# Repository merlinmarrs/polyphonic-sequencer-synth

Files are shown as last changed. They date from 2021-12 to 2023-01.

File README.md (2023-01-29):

# polyphonic-sequencer-synth

**WARNING: This device could destroy your computer's USB port or USB adapter. This device also flashes at high frequency and is an epilepsy risk.**

*NOTE: Not all 74HC14 ICs work for this circuit. Elliot Williams uses the CD40106BE instead. Make sure your 74HC14 has Schmitt trigger with hysteresis and maybe order a couple different brands to be sure. I find that Nexperia ICs work well and not I have had bad luck with Diodes Incorporated.

A mini sequencer and polyphonic synth based directly on Elliot Williams' epic Logic Noise series from Hackaday (https://hackaday.com/2015/02/04/logic-noise-sweet-sweet-oscillator-sounds/).

The boards were designed and manufactured at Fablab Digiscope in Orsay France, which is run by Romain Di Vozzo, by Jonah Marrs with funding from La Diagonale U Paris Saclay. Here's a video of the workshop and the board in action: https://vimeo.com/653720316

Selena Pere has made an beautiful inferface for a version 2 of this device. 

The sequencer portion is an 8-bit looper using a 595 shift register (and a second 595 just to make the corresponding LEDs blink). Bits can be added in LOOP mode by pushing the BEAT button. Beats are automatically added in AUTO mode by synchronizing the CLK and DATA knobs at the far right. The green LED is connected to the CLK frequency. 

The jumpers can trigger one of three notes everytime that corresponding LED flashes. The timber of each note can be varied by turning the pots marked A, B and C. 

The notes are passively mixed in a final stage and can be either output to the onboard buzzer or send to the 3.5mm audio out with OUT selected on the second slide switch. 

The board can be powered by USB C or with a 5V power supply connected to the power header. 

Notes:
-For the device to make predictable sound, there should be at least one jumper going to notes A, B and C from the loop sequence header. 
-If the clock is set too fast it will saturate the shift register resulting in a full set of beats. To remove the beats, turn to AUTO mode and find a combination of CLK and DATA that produces no beats, and then switch back to LOOP mode once the beats have been cleared to make your own pattern. 
-You have to push down hard enough to activate the mini metal button and if the clock is going super slow it might seem likes it's impossible to add beats. Either speed up the CLK or hold the button longer than you would expect is necessary :).
-If you change the output mixing resistors you can change the output volume.

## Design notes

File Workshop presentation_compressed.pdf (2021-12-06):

# Free Synthesizer Workshops @ Fablab Digiscope | LISN

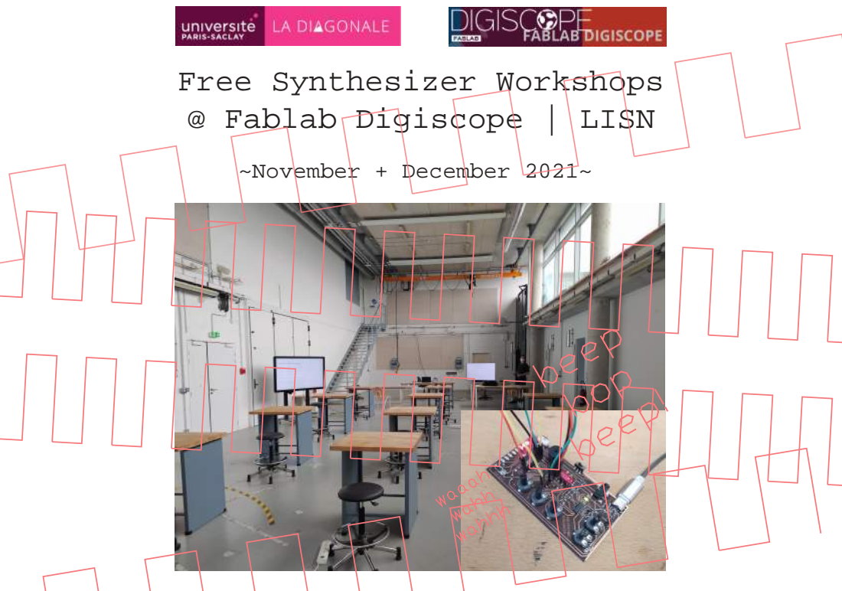
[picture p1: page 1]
~November + December 2021~; beep bop beep!; waaah wahh wahhh

# SAFETY

# THIS BOARD IS

# -IT IS UNINSULATED -IT COULD DAMAGE YOUR PC -YOU SHOULD NOT LEAVE IT PLUGGED IN UNATTENDED -RISK OF EPILEPTIC SEIZURES

# COMMENT SOUDER

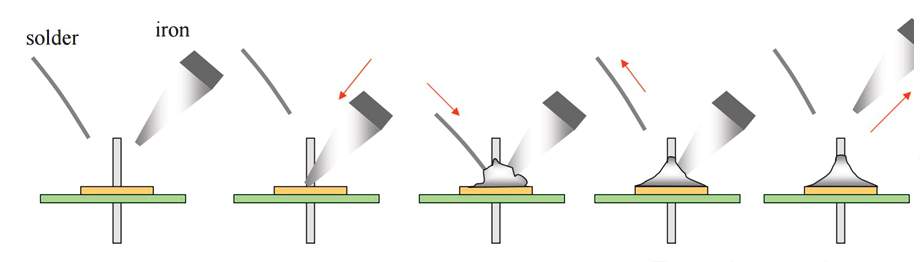
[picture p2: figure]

# IT GETS HOT!

# WASH YOUR HANDS BEFORE YOU EAT (LEAD IN THE SOLDER)

# ASSEMBLY

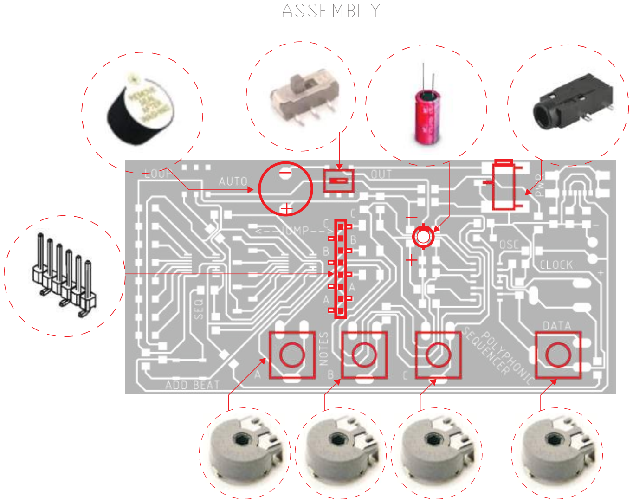
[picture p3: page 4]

# CAPACITOR STORES ELECTRICAL ENERGY HI FREQ PASSES WHILE LOW FREQ BLOCKED

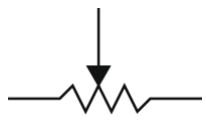
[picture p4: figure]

# POTENTIOMETER A VARIABLE RESISTOR CONTROLS VOLUME IN YOUR STEREO

# SWITCH ALLOWS US TO CONNECT / DISCONNECT BETWEEN TWO OPTIONS LIKE AM / FM ON A RADIO

# PIEZO BUZZER A MINI SPEAKER THAT VIBRATES TO CREATE SOUND

# OPERATION

HIT | TO

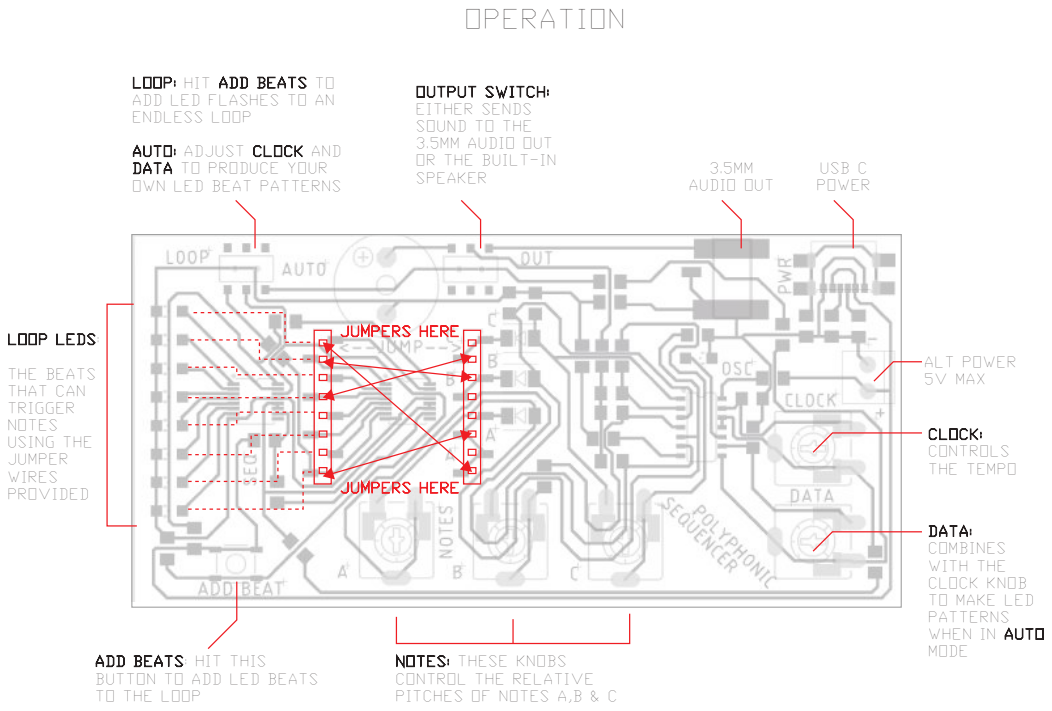
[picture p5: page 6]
ADJUST; AND; : HIT THIS; THESE KNOBS; 3.5MM AUDIO OUT; USB C POWER; ALT POWER 5V MAX; CONTROLS THE TEMPO; THE BEATS THAT CAN TRIGGER NOTES USING THE JUMPER WIRES PROVIDED

ADD LED FLASHES TO AN
ENDLESS LOOP

EITHER SENDS
SOUND TO THE
3.5MM AUDIO OUT
OR THE BUILT-IN
SPEAKER

TO PRODUCE YOUR
OWN LED BEAT PATTERNS

COMBINES
WITH THE
CLOCK KNOB
TO MAKE LED
PATTERNS
WHEN IN
MODE

BUTTON TO ADD LED BEATS
TO THE LOOP

CONTROL THE RELATIVE
PITCHES OF NOTES A,B & C

# RESEARCH

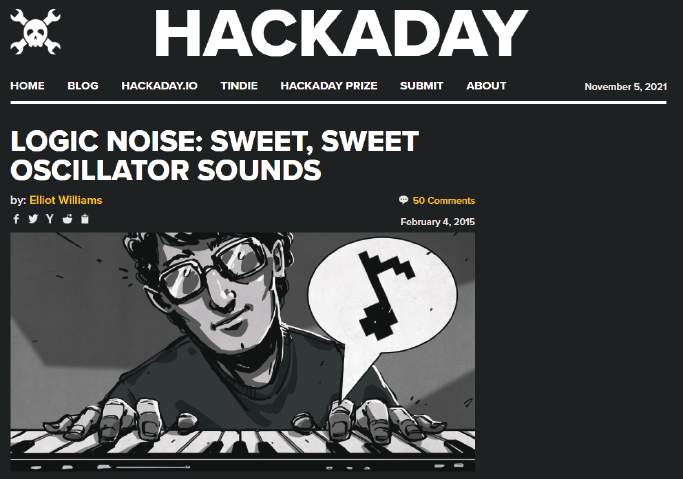
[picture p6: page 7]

# PROTOTYPING

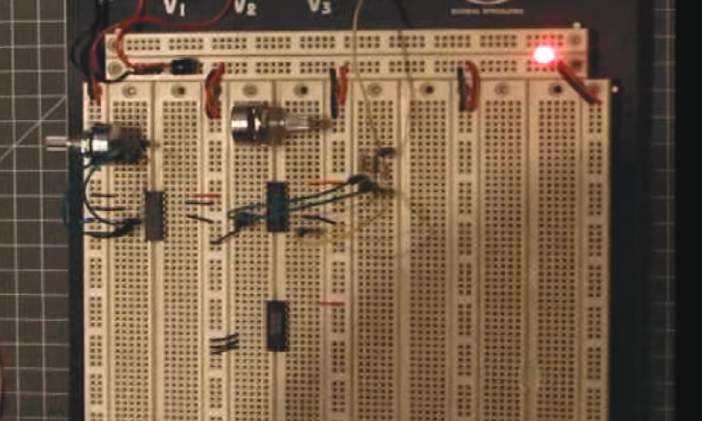
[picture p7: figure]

# SOURCING

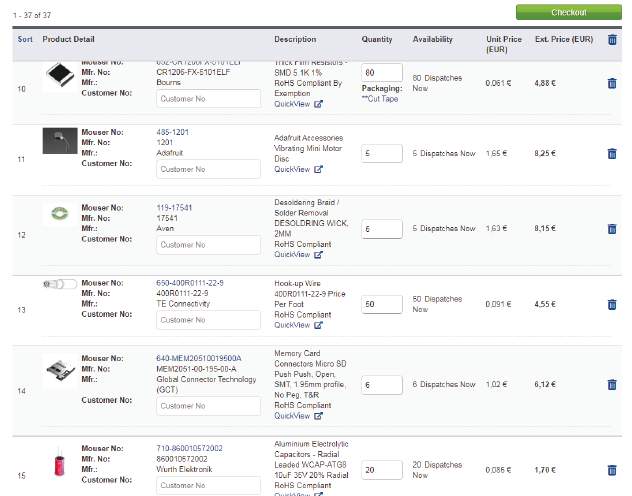
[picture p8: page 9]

# DESIGN

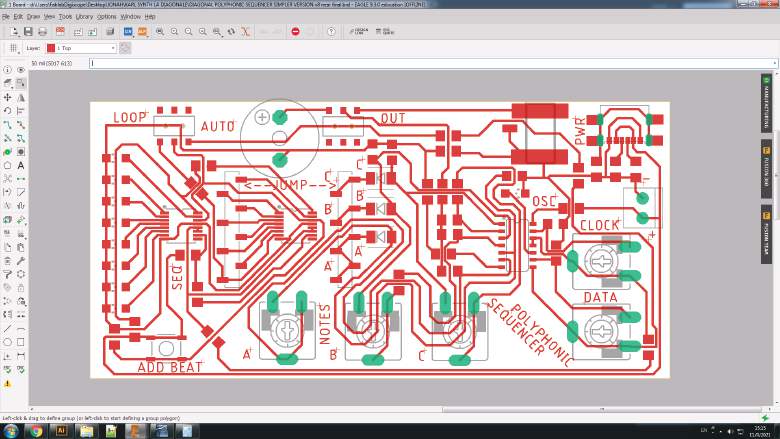
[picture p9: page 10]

# PRODUCTION

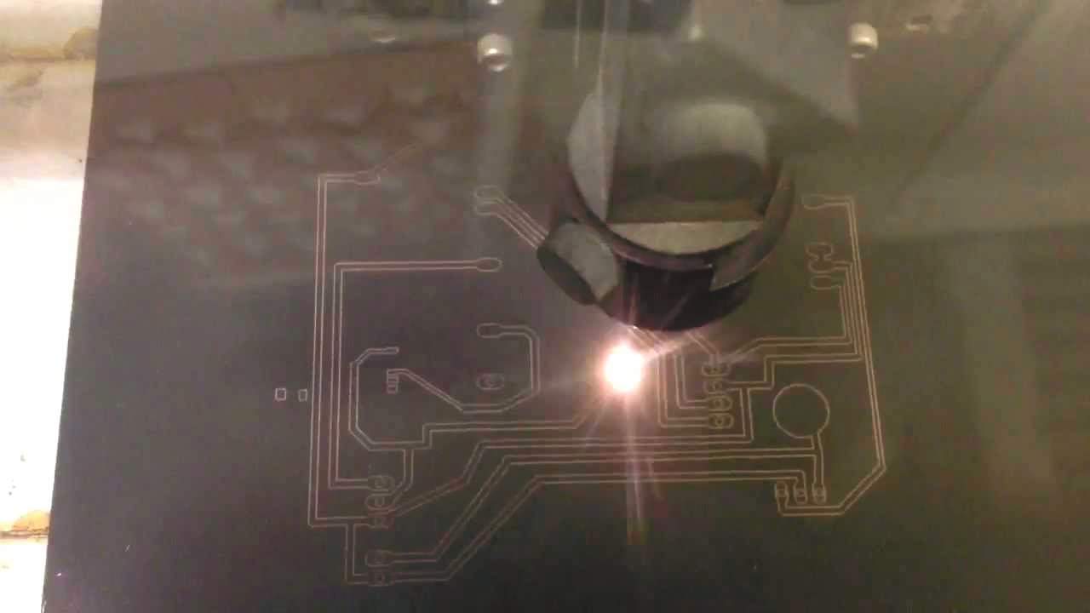
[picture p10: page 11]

# INVERTER

YES | NO

# INVERTER

NO | YES

# INVERTER

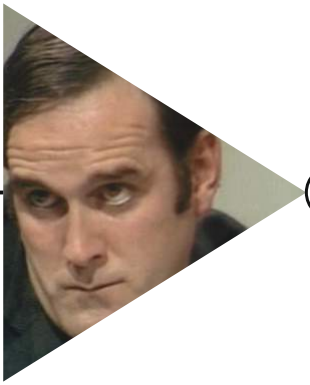
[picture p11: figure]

“YES,

# I DID!”

“NO,

# YOU DIDN’T”

# DIDN’T”

# INVERTER

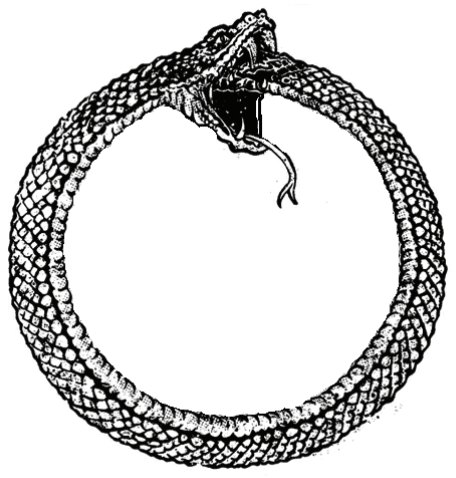
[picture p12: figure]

# YES

t = 0

# delay

# YES

# INVERTER

t = 1

# delay

NO | NO

# INVERTER

t = 0 | 1 | 2 | 3 | 4

# NO YES NO YESNO

# Sound Is Just Wiggly Air !

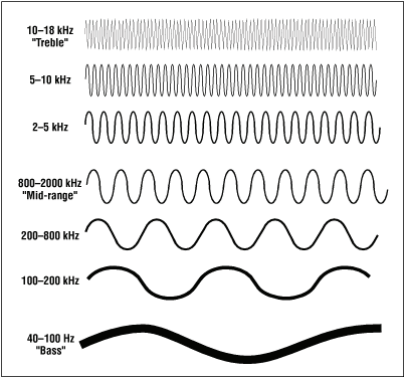
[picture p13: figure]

# PIEZO SPEAKER

# SWAMP

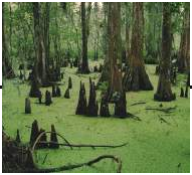
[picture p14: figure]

OPERATION | OPERATION

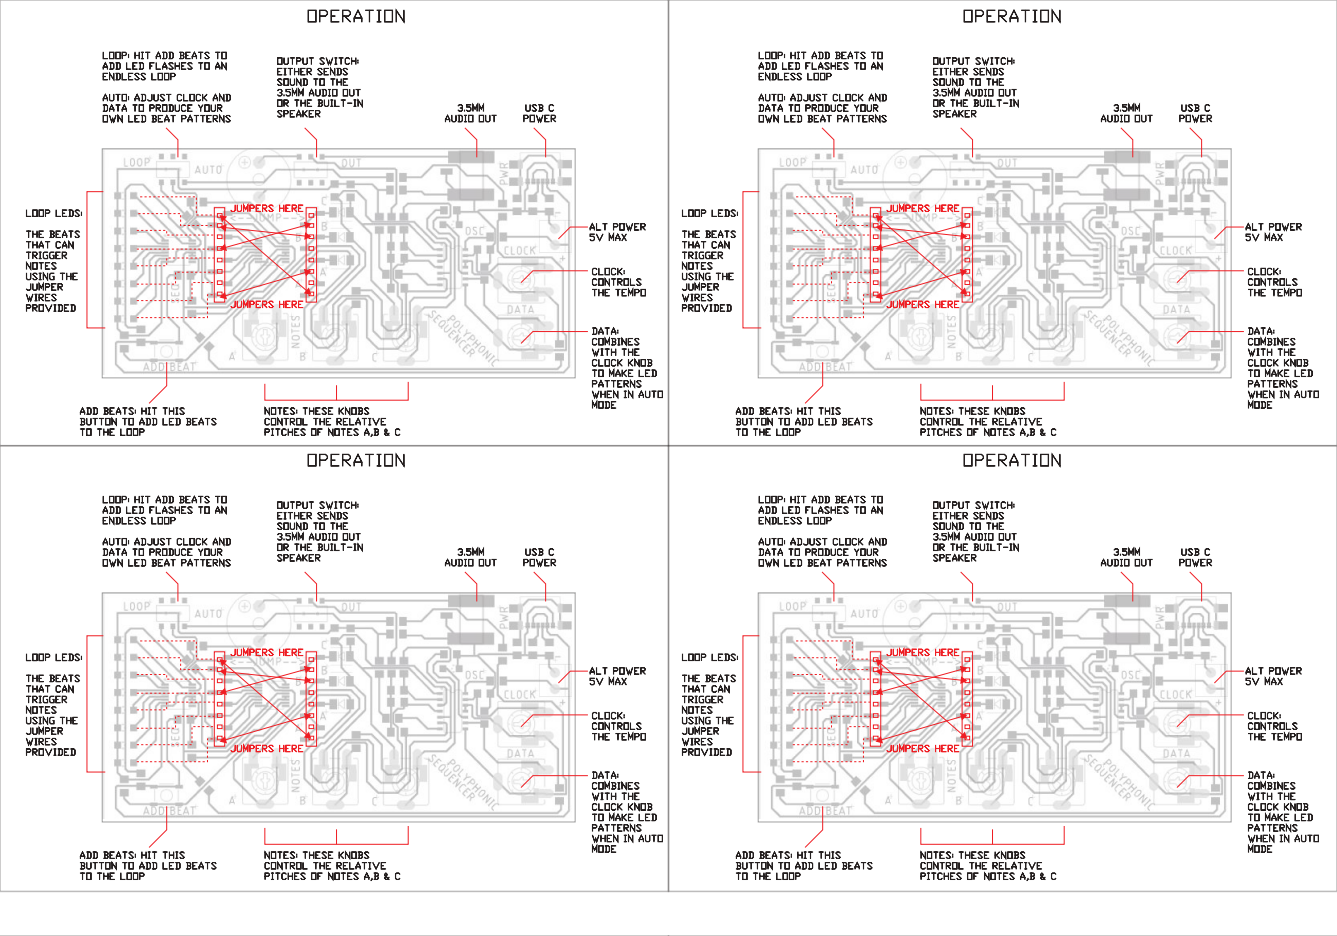
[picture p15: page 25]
OPERATION; HIT; ADD; LED; FLASHES TO; ENDLESS LOOP; ADJUST; AND; PRODUCE YOUR; OWN; LED BEAT PATTERNS; SOUND TO; THE; 3.5MM AUDIO; OUT; HIT THIS; BUTTON TO; LED BEATS; LOOP; THESE KNOBS; PITCHES; OF NOTES A,B & C; AUDIO; USB C POWER; ALT POWER 5V MAX; CONTROLS THE TEMPO; COMBINES; WITH; CLOCK KNOB; MAKE LED; PATTERNS WHEN IN MODE; THE BEATS THAT CAN TRIGGER NOTES USING THE JUMPER WIRES PROVIDED; LED FLASHES TO; ENDLESS; MAKE; LOOP:; HIT ADD BEATS TO; DATA TO; 3.5MM AUDIO OUT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

EITHER SENDS
OR THE BUILT-IN
SPEAKER

SOUND TO THE

CONTROL THE RELATIVE

ADD LED FLASHES TO AN
ENDLESS LOOP

OUTPUT SWITCH:

3.5MM AUDIO OUT

AUTO: ADJUST CLOCK AND

TO PRODUCE YOUR
OWN LED BEAT PATTERNS

COMBINES
WITH THE
CLOCK KNOB
TO MAKE LED
PATTERNS
WHEN IN
MODE

ADD BEATS: HIT THIS
BUTTON TO ADD LED BEATS
TO THE LOOP

NOTES: THESE KNOBS
PITCHES OF NOTES A,B & C

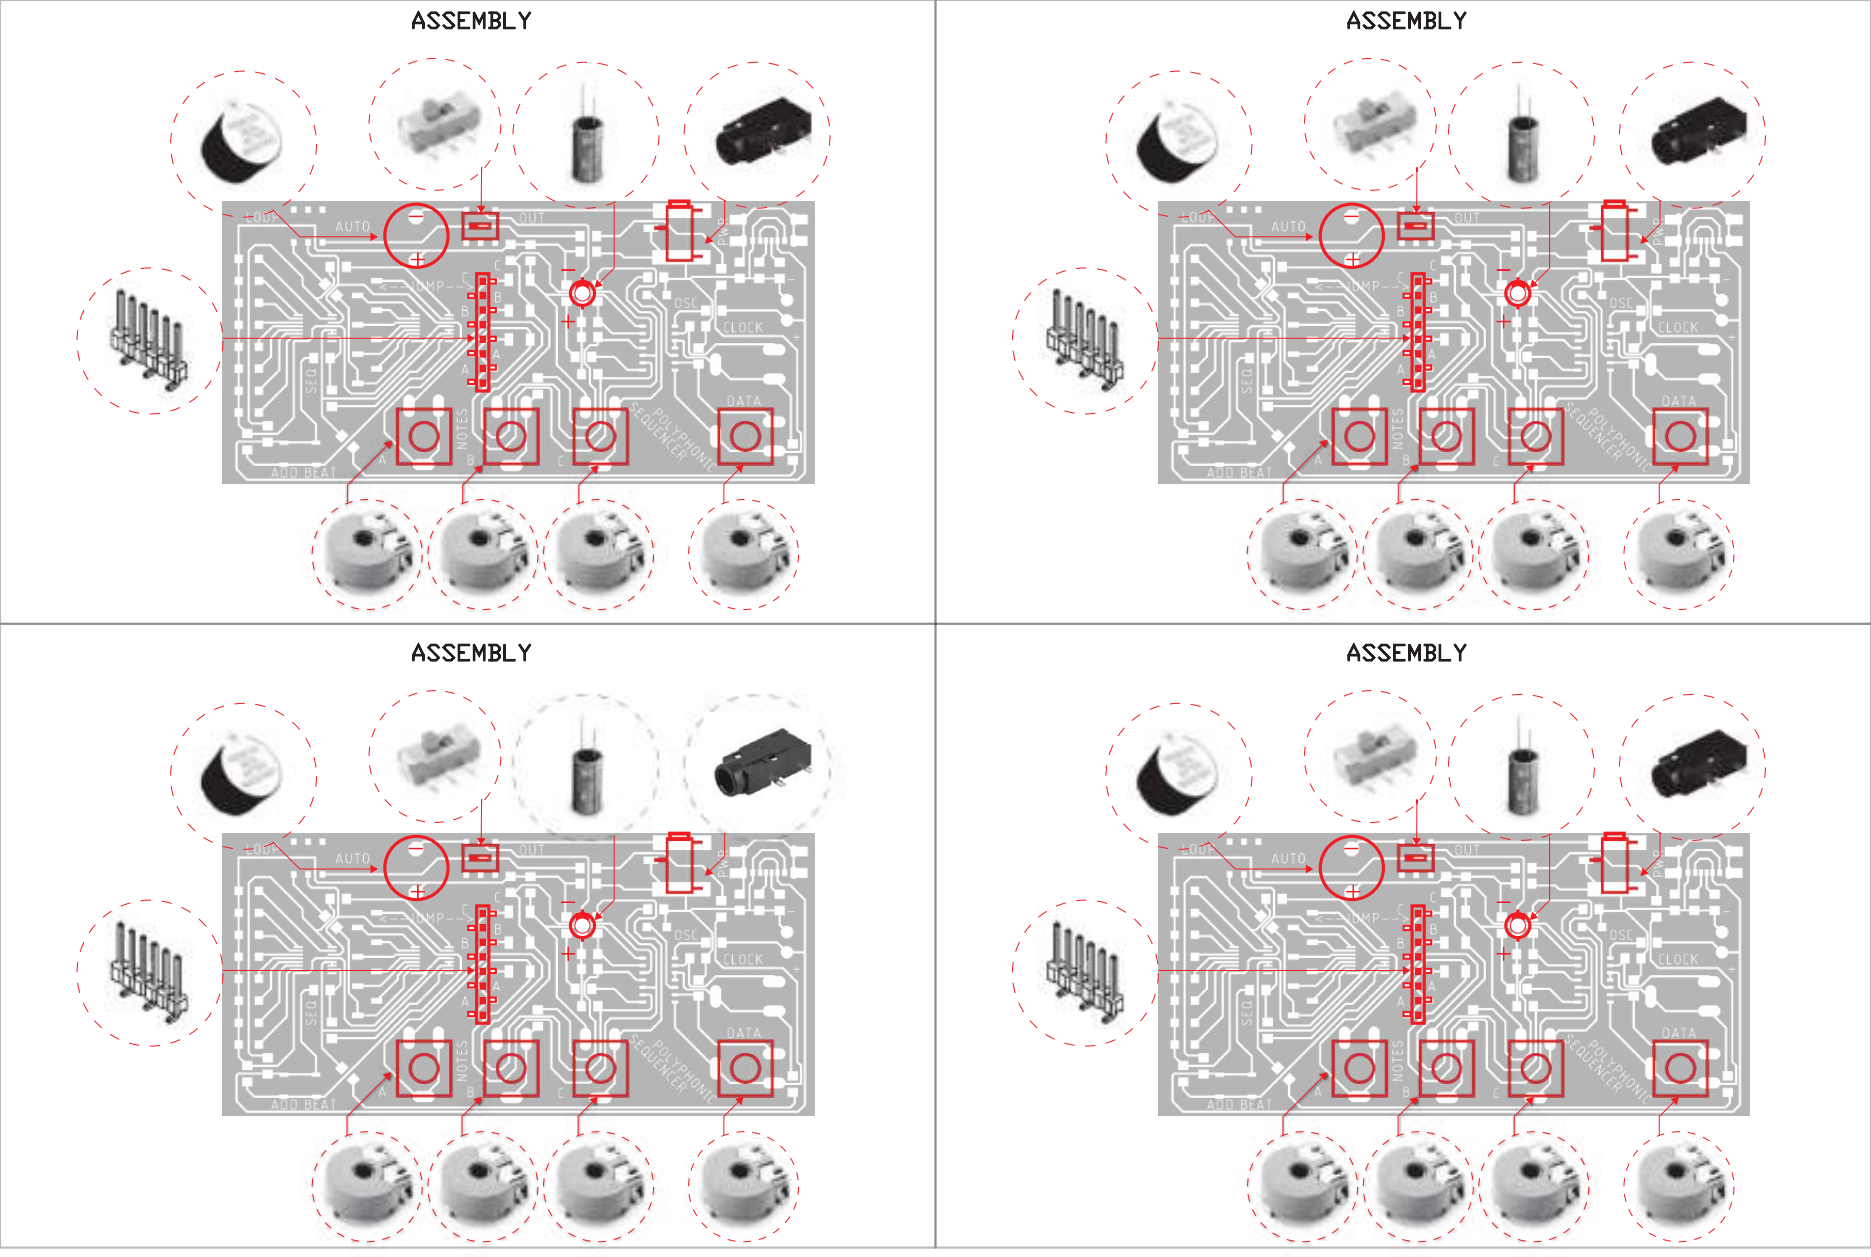
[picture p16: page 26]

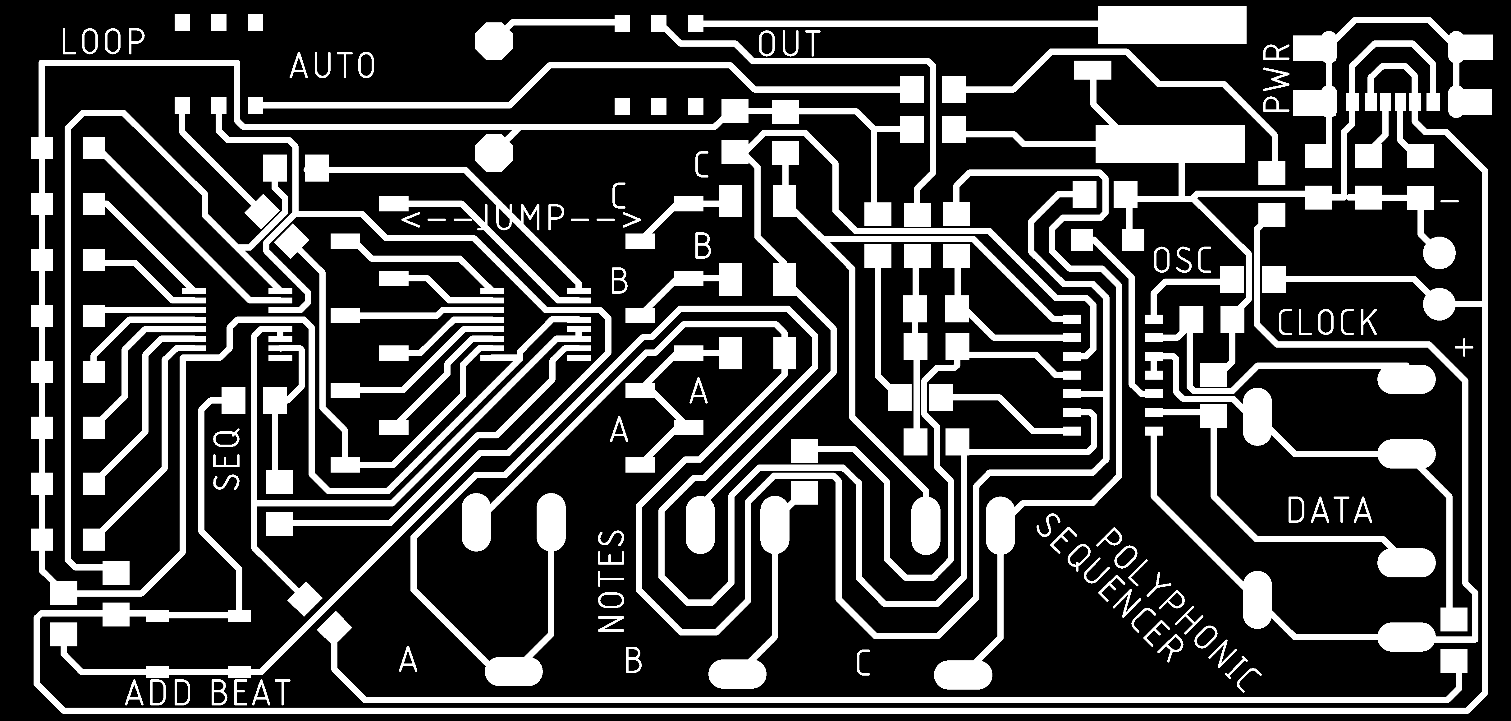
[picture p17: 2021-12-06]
polyphonic sequencer v9 TO CUT inverted.png

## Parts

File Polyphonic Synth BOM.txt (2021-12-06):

BOM:

x1 Hex inverter with Schmitt-Trigger Inputs 74HC14 *in SOIC-14*
https://www.mouser.fr/ProductDetail/Texas-Instruments/SN74HC14NS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

x2 Shift register 74HC595PW-Q100 *in TSSOP-16* :
https://www.mouser.fr/ProductDetail/771-74HC595PW-Q100

x1 USB C port :
https://www.mouser.fr/ProductDetail/640-USB4125-GF-A

x5 50K pot PS10MV50-503A3030:
https://www.mouser.fr/ProductDetail/531-PS10MV50503A3030

x4 Black knobs 5119NE:
https://www.mouser.fr/ProductDetail/531-5119NE

x1 Cream shaft 5116:
https://www.mouser.fr/ProductDetail/531-5116

x1 button PTS526 SK15 SMTR2 LFS:
https://www.mouser.fr/ProductDetail/611-PTS526SK15SMR2L

x2 slide switch JS202011SCQN:
https://www.mouser.fr/ProductDetail/611-JS202011SCQN

x1 set of 8 female-female jumpers ZW-FF-10:
https://www.mouser.fr/ProductDetail/854-ZW-FF-10

x3 SMD diodes BAS321,115:
https://www.mouser.fr/ProductDetail/771-BAS321-T-R 

x2 SMD header 1x8 87898-0826:
https://www.mouser.fr/ProductDetail/538-87898-0826

x1 buzzer 
https://www.mouser.fr/ProductDetail/665-AT1224TWT5V2R

x1 3.5mm jack SJ2-35853A-SMT-TR:
https://www.mouser.fr/ProductDetail/490-SJ2-35853ASMT-TR

x1 header screw terminal
https://www.mouser.fr/ProductDetail/651-1984167

Generic components:

x1 green 1206 SMD LED

x8 red 1206 SMD LED

x2 47uF SMD 1206 cap

x15 0ohm jumper 1206 SMD LED

x1 0.1uF SMD 1206 cap

x1 1uF SMD 1206 cap

x1 10uF SMD 1206 cap

x1 100uF cap

x2 10K SMD 1206 resistor

x3 100ohm SMD 1206 resistor

x2 5k1 SMD 1206 resistor

x1 1M SMD 1206 resistor

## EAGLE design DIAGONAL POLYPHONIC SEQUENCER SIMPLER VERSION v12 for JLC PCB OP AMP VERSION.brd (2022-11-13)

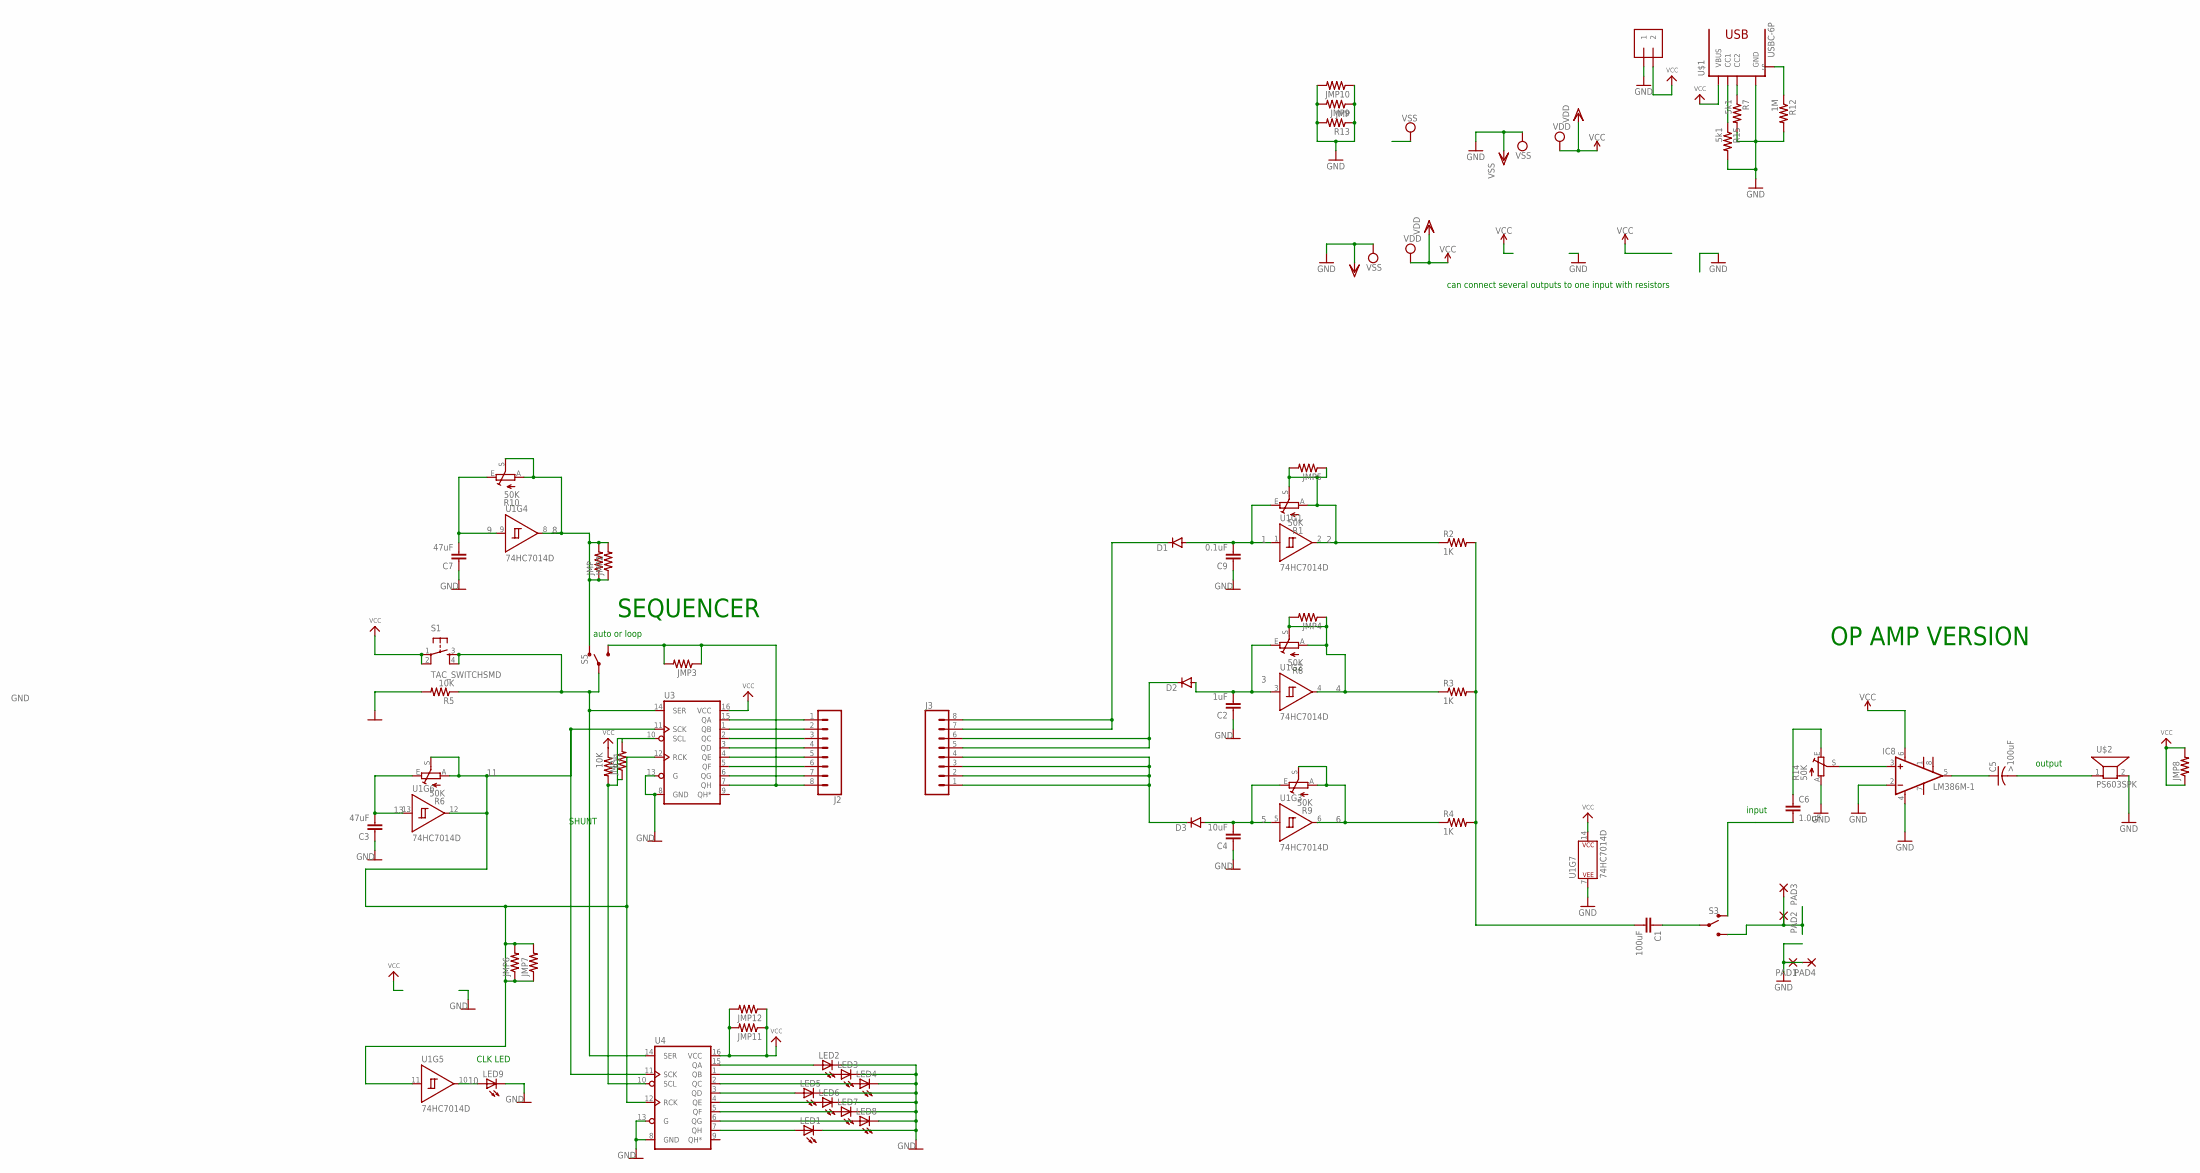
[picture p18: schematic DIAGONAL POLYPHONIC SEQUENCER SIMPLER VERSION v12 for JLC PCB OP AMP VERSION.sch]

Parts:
C1: 100uF; 1206
C2: 1uF; 1206
C3, C7: 47uF; 1206
C4: 10uF; 1206
C5: >100uF; C1206
C6: 1.0uF; 1206
C9: 0.1uF; 1206
D1, D2, D3: DIODEDO214AA; DO-214AA
IC8: LM386M-1; SO08
J1: 1X2-3.5MM
J2, J3: CONN_08SMD-STRAIGHT-ALT-FEMALE; 1X08_SMD_ALT
JMP, JMP1, JMP2, JMP3, JMP4, JMP5, JMP6, JMP7, JMP8, JMP9, JMP10, JMP11, JMP12: R-US_R1206; R1206
LED1, LED2, LED3, LED4, LED5, LED6, LED7, LED8, LED9: LEDCHIPLED_1206; CHIPLED_1206
PAD1, PAD2, PAD3, PAD4: SMD5; SMD2,54-5,08
R1, R6, R8, R9, R10, R14: 50K; CA9V
R2, R3, R4: 1K; R1206
R5, R11: 10K; R1206
R7, R15: 5k1; R1206
R12: 1M; R1206
R13: JMP; R1206
S1: TAC_SWITCHSMD; TACTILE-SWITCH-SMD
S3, S5: SWITCH-SPDT-SMD-AYZ0202; SWITCH_DPDT_SMD_AYZ0202
U1: 74HC7014D; SO14
U3, U4: 74595; TSSOP16
U$1: USBC-6P; USCX-06FX-XXMX-01
U$2: PS603SPK; PS603

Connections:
1: C9.2, D1.A, R1.E, U1.1 (A)
2: JMP5.1, JMP5.2, R1.A, R1.S, R2.1, U1.2 (Y)
3: C2.2, D2.A, R8.E, U1.3 (A)
4: JMP4.1, JMP4.2, R3.1, R8.A, R8.S, U1.4 (Y)
5: C4.2, D3.A, R9.E, U1.5 (A)
6: R4.1, R9.A, R9.S, U1.6 (Y)
8: JMP.1, JMP.2, JMP2.1, JMP2.2, R10.A, R10.S, S5.1 (O), U1.8 (Y)
9: C7.2, R10.E, U1.9 (A)
10: LED9.A, U1.10 (Y)
11: JMP6.1, JMP6.2, JMP7.1, JMP7.2, R6.A, R6.S, U1.11 (A), U1.12 (Y), U3.11 (SCK), U3.12 (RCK), U4.11 (SCK), U4.12 (RCK)
13: C3.2, R6.E, U1.13 (A)
GND: C2.1, C3.1, C4.1, C7.1, C9.1, IC8.2 (-IN), IC8.4 (GND), J1.1, JMP9.1, JMP9.2, JMP10.1, JMP10.2, LED1.C, LED2.C, LED3.C, LED4.C, LED5.C, LED6.C, LED7.C, LED8.C, LED9.C, PAD1.1, PAD4.1, R5.2, R7.2, R12.2, R13.1, R13.2, R14.A, R15.2, U1.7 (P$V-), U3.8 (GND), U3.13 (G), U4.8 (GND), U4.13 (G), U$1.GND1 (GND), U$1.GND2 (GND), U$2.2
unnamed: LED1.A, U4.7 (QH)
unnamed: C1.2, R2.2, R3.2, R4.2
unnamed: LED4.A, U4.2 (QC)
unnamed: R7.1, U$1.CC2
unnamed: LED2.A, U4.15 (QA)
unnamed: LED3.A, U4.1 (QB)
unnamed: C1.1, S3.2
unnamed: J2.1, U3.15 (QA)
unnamed: J2.2, U3.1 (QB)
unnamed: LED7.A, U4.5 (QF)
unnamed: LED6.A, U4.4 (QE)
unnamed: LED8.A, U4.6 (QG)
unnamed: LED5.A, U4.3 (QD)
unnamed: D3.C, J3.1, J3.2, J3.3, J3.4
unnamed: D2.C, J3.5, J3.6
unnamed: R15.1, U$1.CC1
unnamed: J2.3, U3.2 (QC)
unnamed: PAD2.1, PAD3.1, S3.3 (S)
unnamed: C6.2, S3.1 (O)
unnamed: J2.4, U3.3 (QD)
unnamed: R12.1, U$1.SHIELD1 (S), U$1.SHIELD2 (S), U$1.SHIELD3 (S), U$1.SHIELD4 (S)
unnamed: D1.C, J3.7, J3.8
unnamed: J2.5, U3.4 (QE)
unnamed: J2.6, U3.5 (QF)
unnamed: J2.7, U3.6 (QG)
unnamed: J2.8, JMP3.1, JMP3.2, S5.3 (S), U3.7 (QH)
unnamed: R5.1, S1.3, S1.4, S5.2, U3.14 (SER), U4.14 (SER)
unnamed: JMP1.1, JMP1.2, R11.2, U3.10 (SCL), U4.10 (SCL)
unnamed: IC8.3 (+IN), R14.S
unnamed: C5.1, IC8.5 (OUT)
unnamed: C5.2, U$2.1
unnamed: C6.1, R14.E
VCC: IC8.6 (VS), J1.2, JMP8.1, JMP8.2, JMP11.1, JMP11.2, JMP12.1, JMP12.2, R11.1, S1.1, S1.2, U1.14 (P$V+), U3.16 (VCC), U4.16 (VCC), U$1.VBUS1 (VBUS), U$1.VBUS2 (VBUS)

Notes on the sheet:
auto or loop
can connect several outputs to one input with resistors
SEQUENCER
SHUNT
CLK LED
input
output
OP AMP VERSION

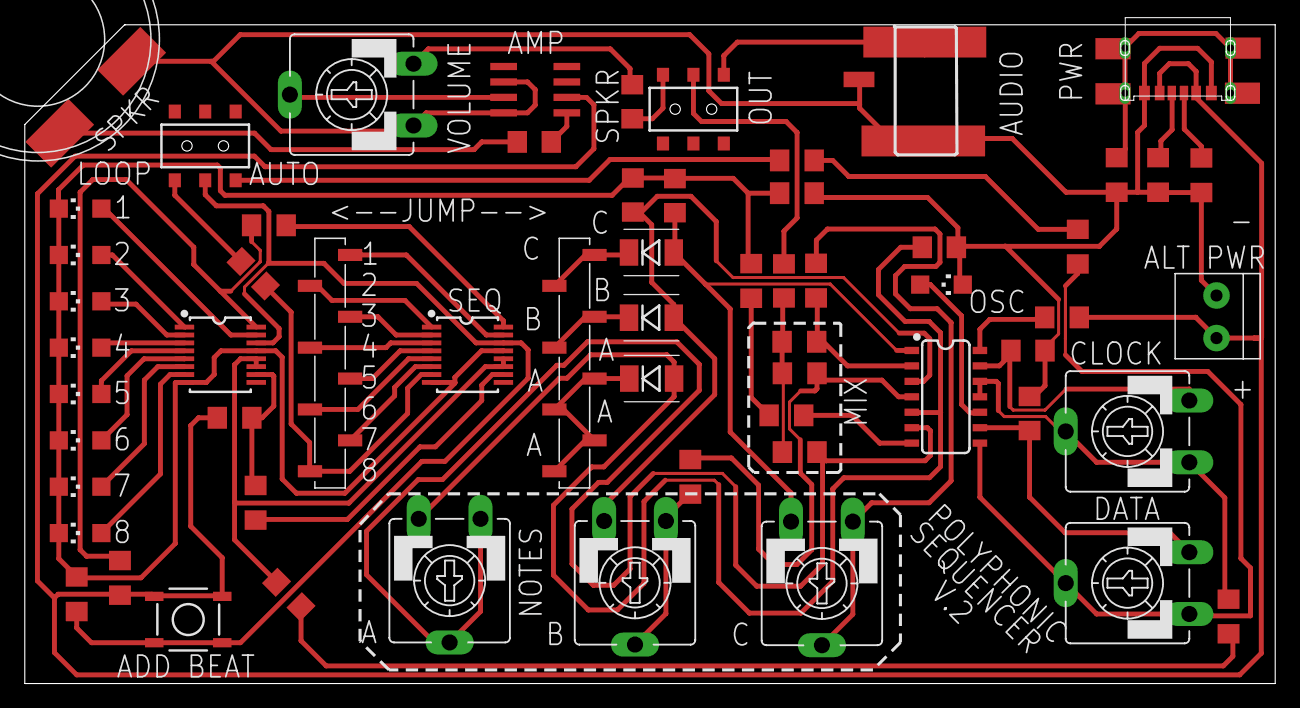
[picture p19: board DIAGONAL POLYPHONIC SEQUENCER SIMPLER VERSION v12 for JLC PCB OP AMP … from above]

Board: 2 copper layers, 102.8 x 54.2 mm, 64 parts (0 on the bottom side), 45 nets.

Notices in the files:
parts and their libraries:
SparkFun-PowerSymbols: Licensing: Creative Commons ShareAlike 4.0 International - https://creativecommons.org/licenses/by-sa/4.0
